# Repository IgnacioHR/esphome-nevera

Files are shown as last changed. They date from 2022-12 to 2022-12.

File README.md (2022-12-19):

# Nevera - Fridge Alarm

## Introduction

We experienced an issue with our fridge where the door was difficult to open immediately after it had been closed. This is due to the fact that the cold air inside the fridge reduces in volume, causing the rubber on the door frame to take longer to fill the void. If you try to open the door too early, it puts additional strain on the rubber. In order to address this issue, we have developed a device that serves several purposes.

## Demo

Check out this video: <https://youtu.be/vCrqtjIsVMY>. The first 30 seconds show the device operating normally, while the rest of the video demonstrates a bug that we have yet to fix.

## Project Goals

1. Sound a loud alarm if the fridge door is opened too early (the time can be adjusted)
1. Inform the user how long they should wait to open the door
1. Provide information to a home automation system (HA) about the status of three sensors:
   1. Main door sensor (open/closed)
   1. Wait time sensor (on/off)
   1. Alarm sensor (on/off)
1. In addition to the above sensors, We have also added a statistics sensor to the HA to track the following information over the past 24 hours
   1. The number of times the firdge door was opened/closed
   1. The amount of time the fridge door was left open

## Bill of Materials (BOM)

- ESP32 single chip
- MAX7219 8x8 LED matrix - used as the main display (communication via SPI protocol)
- Voltage regulator to 3.3v - (used to power the ESP32 with an external 5v power supply)
- Active buzzer (alarm - Google "MH-FMD")
- 8 channel bi-directional logic level converter (Google "HW-0108")
- Reed Switch Sensor Magnetic (and magnet)

## Images

Wiring phase:

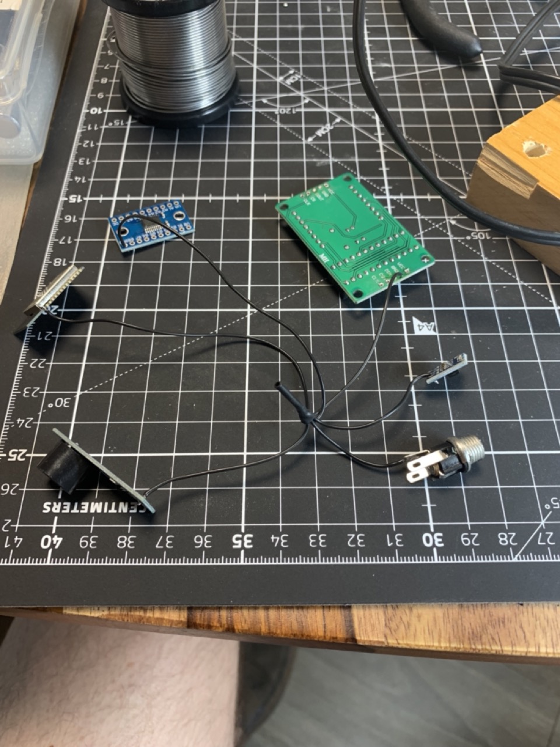
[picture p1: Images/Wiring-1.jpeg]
Wiring 1, GND

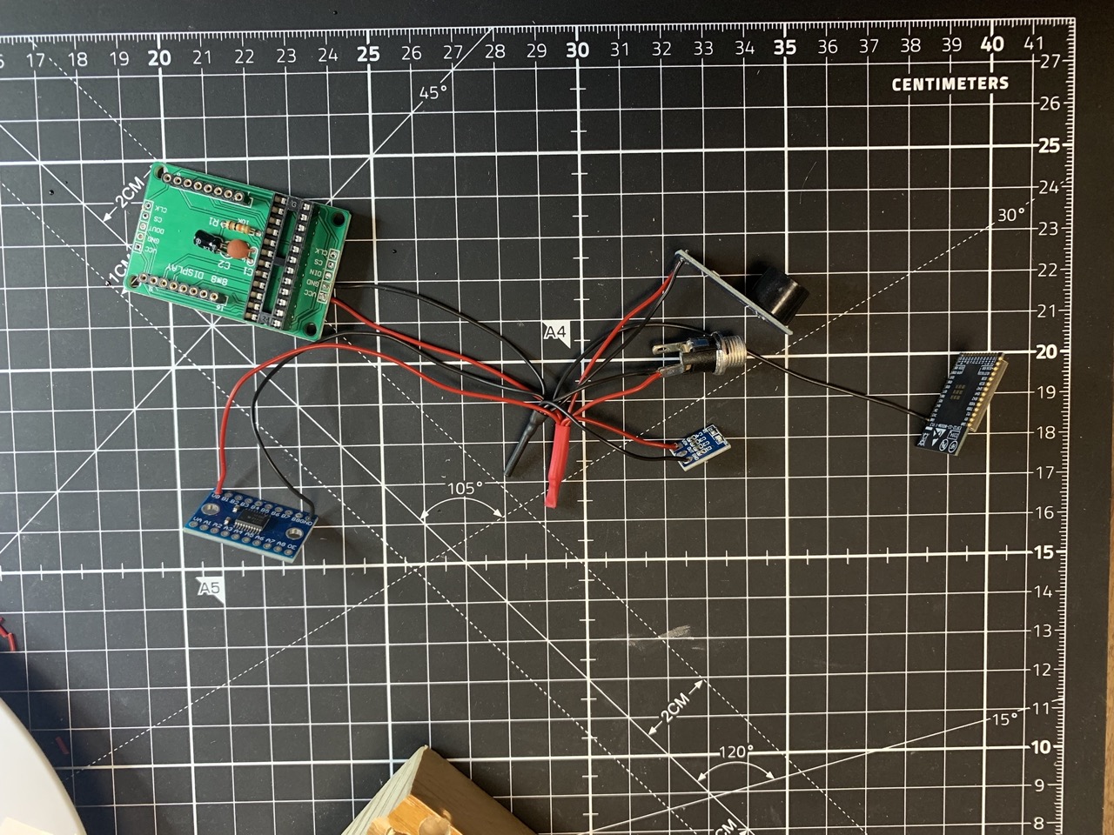
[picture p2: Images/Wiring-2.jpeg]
Wiring 2, +5v

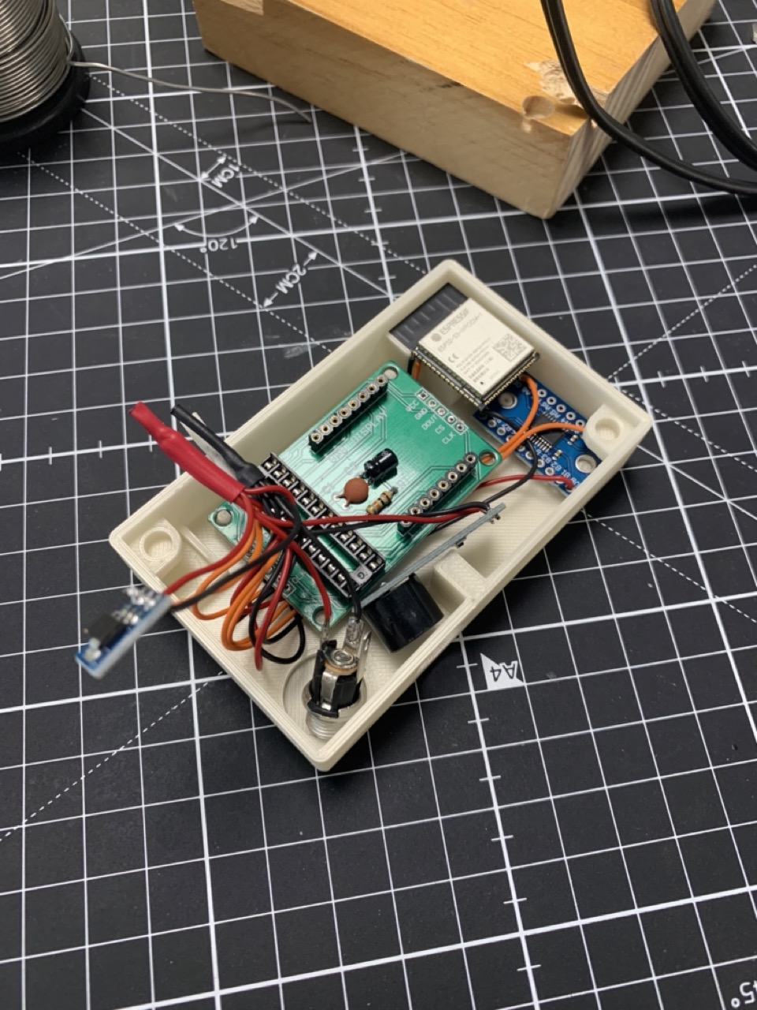
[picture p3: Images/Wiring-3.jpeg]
Wiring 3, +3.3v

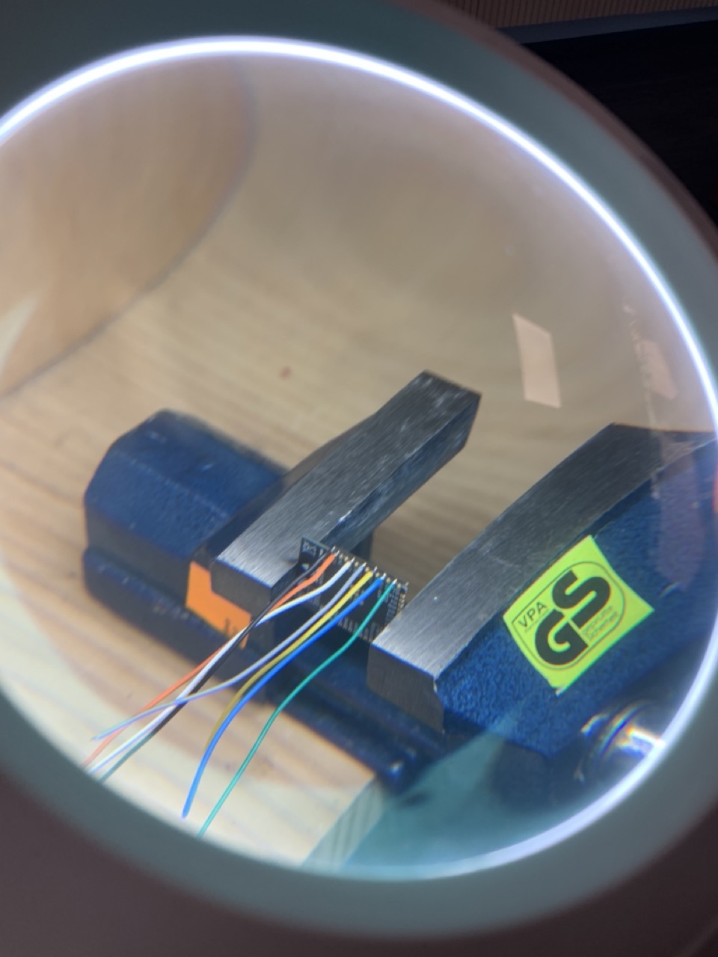
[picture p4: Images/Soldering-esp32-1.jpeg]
Soldering esp32, details

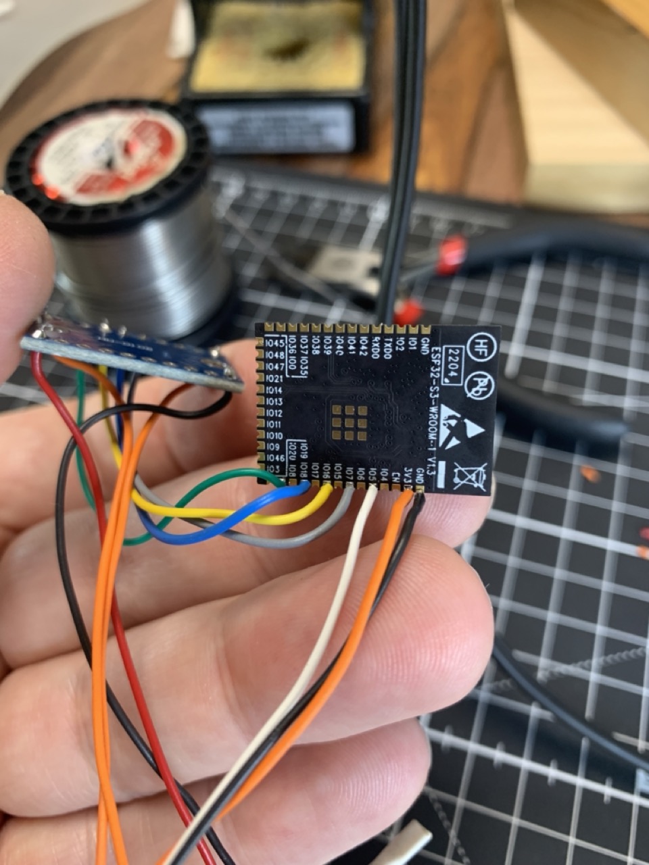
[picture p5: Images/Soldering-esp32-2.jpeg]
Soldering esp32, details

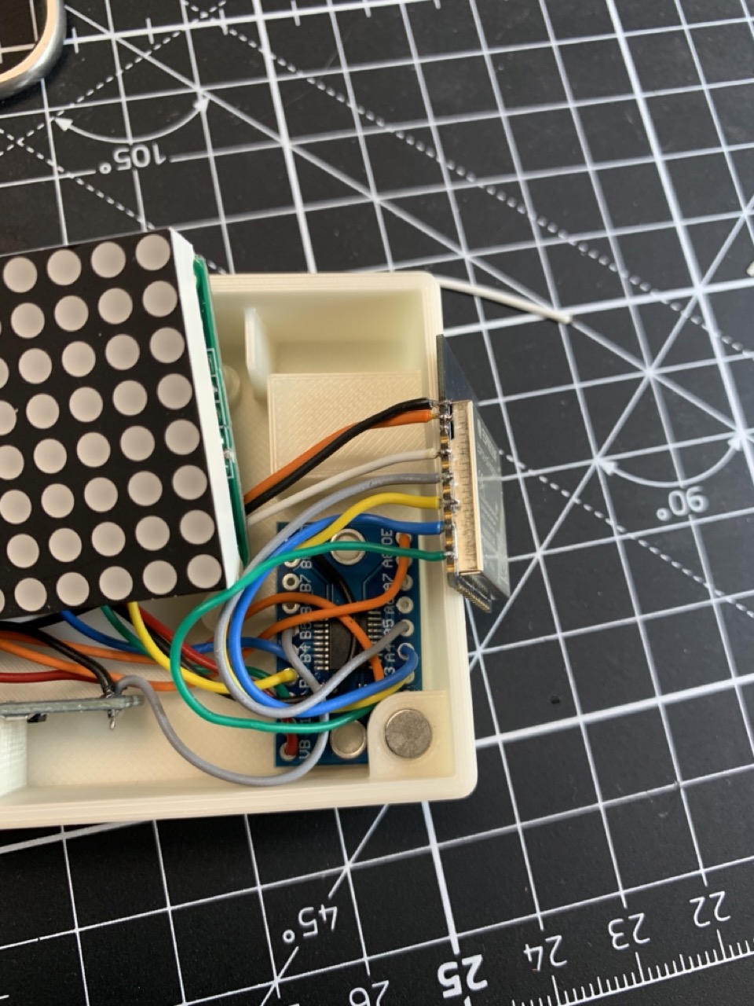
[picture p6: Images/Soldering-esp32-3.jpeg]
Soldering esp32, details

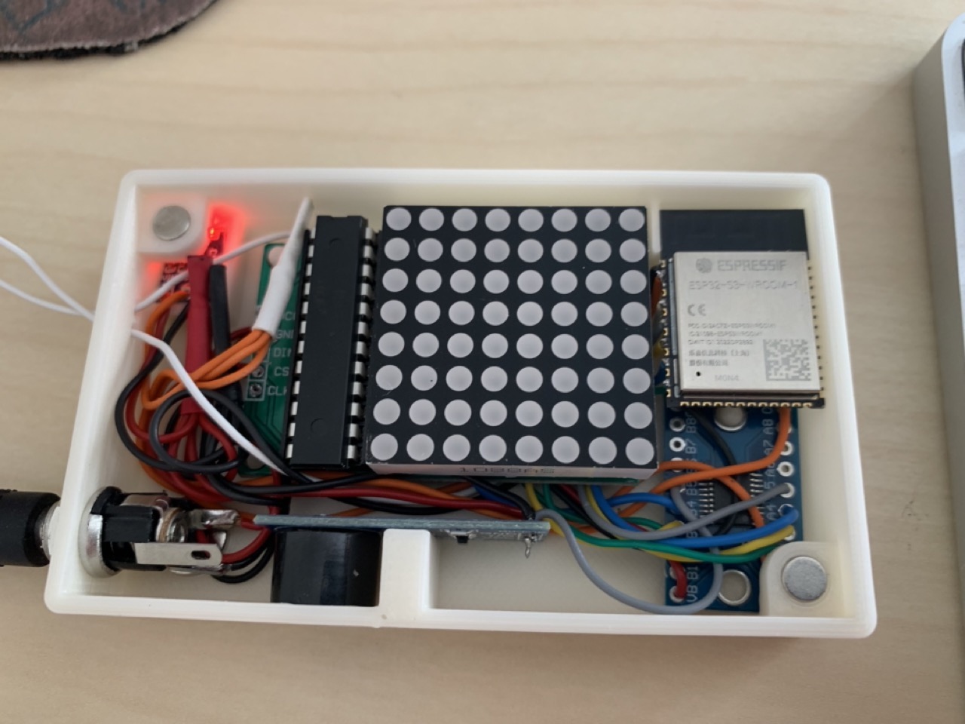
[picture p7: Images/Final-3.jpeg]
Final, open

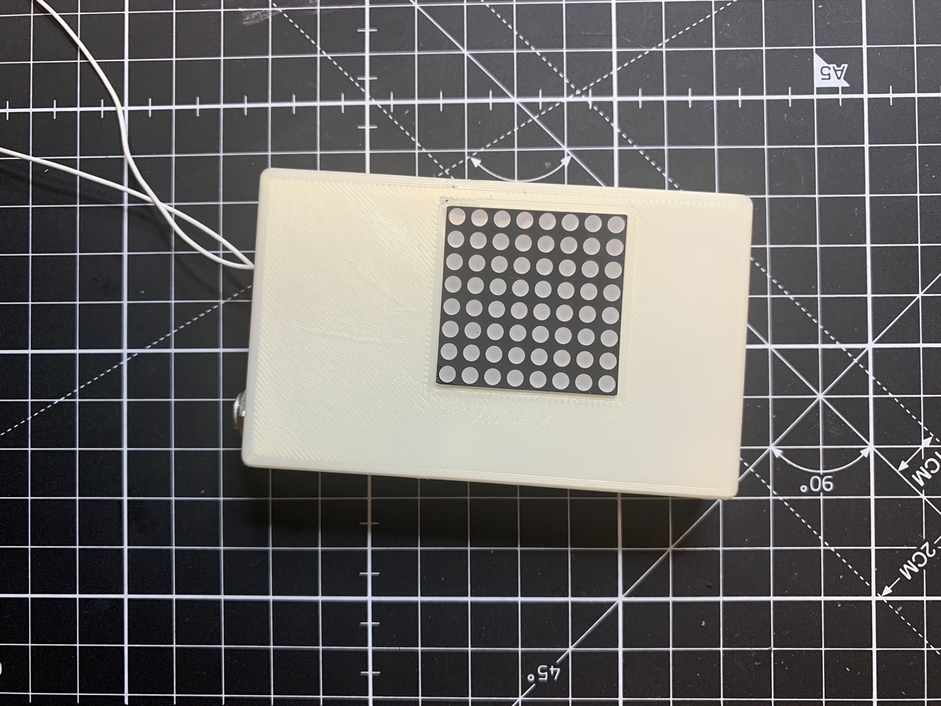
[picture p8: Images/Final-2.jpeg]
Final, closed


## Schematics

TODO

## Case stl for 3d printing

Files in the 3d-printing folder corresponds with the enclosing case. I'm using 4 cilynder 5x3 mm magnets to secure the case closed while allowing me to open it when needed.

Check out the following files:

- 3d-printing/Nevera-case-bottom.stl
- 3d-printing/Nevera-case-top.stl

## Prerequisites

- ESPHome development environment <https://esphome.io/index.html>

## Installation instructions

To install the device, simply copy the file 'nevera.yaml' to your ESPHome development environment and burn it onto a chip.

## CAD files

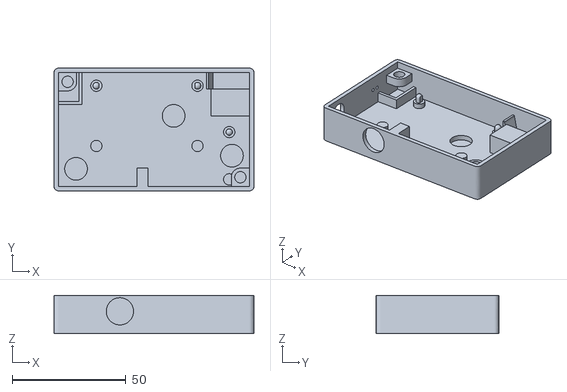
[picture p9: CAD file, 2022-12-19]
3d-printing/Nevera-case-bottom.stl
88.0 x 54.0 x 16.8

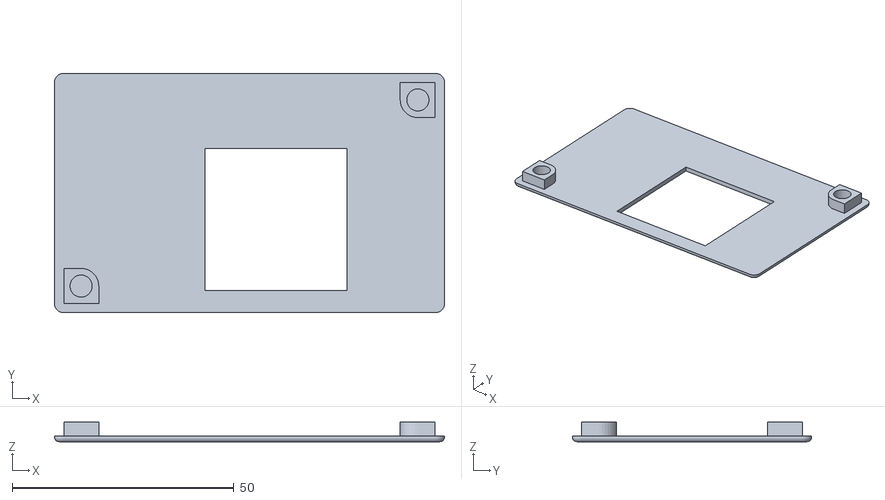
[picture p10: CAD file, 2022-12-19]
3d-printing/Nevera-case-top.stl
88.0 x 54.0 x 4.40

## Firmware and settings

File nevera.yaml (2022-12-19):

# This file is copyright Ignacio Hernández-Ros ignacio@hernandez-ros.com all rights are reserved
# You cannot earn money based on this work and cannot transfer it to anyone that might earn money
# based on this work.
# You can't sell this code. You can't produce the device described for commercial purposes
#
# esphome-nevera is a decive with a sensor that detects when the fridge door has been opened
# Once it is opened:
#   If the last time it was closed is less than 30 seconds, the alarm is turn ON
#   regardeless of the alarm status, the display shows an icon representing "door open"
# When the door is closed:
#   If the alarm was ON, turn it OFF
#   Start a counter down for 30 seconds to detect if it is opened too early
#   The display shows full white and every 30/64 milliseconds a led is turned down (randomly)
# When the count down ends, the fridge door can be safely opened again
#
# The implementation is based on the following devices:
#   SPI to communicate with the MAX7219
#   BinarySensor based on an incoming pin (the contact is magnetic)
#   Template Binary sensor to publish the state of the internal counter (like a tampering device)
#   Switch (internal) to turn the alarm on-off
#
#
#  IMPLEMENTATION NOTES:
#   - I've been extremely careful to avoid interferences between the display and the sensors.
#     Means there are no calls to update the display when the sensor changes. It is the
#     Lambda that render the display who takes care of the status.
#   - The code inside the lambda has been simplified a lot. On every "frame" the entire device
#     Matrix is transferred from the internal 8x8 bits representation to the data model of the
#     surrounding display.
#   - The display is turned "off" when the count down ends. And it is turned "on" when
#     the door has been opened.
#   - There must be a bug in the SPI, Display or binary sensor code that is weird. When the
#     door is closed, sometimes (not always) the display goes black. Internally the whole
#     count down process continues to run. If the door is opened, the alarm turns on, etc.
#     but there is no white representation and no leds are turned off (visually)
#   - Sometimes (randomly) when the fridge door is opened, the intensity is no longer level 15
#   - Sometimes (randomly) the lines are displaced one bit (right) or turned reverse color from a
#     specific led in the line.
#   - It looks like the BinarySensor based on GPIO might interrupt the Display routine (and the
#     SPI transfer) and this causes weird situations?
#
#
# Connections and pin assignments
#
# ESP32 GND    -> 1  -> MAX7219 GND
# ESP32 V3.3v  -> 2  -> MAX7219 VCC
# ESP32 V3.3v  -> 3  -> MAX7219 VCC En (chip enabled)
# ESP32 GPIO32 -> 8  -> Door open sensor IN White
# ESP32 GPIO33 -> 9  -> MAX7219 CS OUT Yellow
# ESP32 GPIO25 -> 10 -> MAX7219 CLK OUT Blue
# ESP32 GPIO27 -> 12 -> MAX7219 DIN OUT Green
# ESP32 GPIO14 -> 13 -> Sound Alarm OUT Grey

esphome:
  name: nevera
  on_boot:
    priority: 600
    then:
      - binary_sensor.template.publish:
          id: sensor_recien_cerrada
          state: OFF
      - binary_sensor.template.publish:
          id: sensor_alarma
          state: OFF

esp32:
  board: esp32dev
  framework:
    type: arduino

# Enable logging
logger:
  #level: VERBOSE
  level: INFO

# Enable Home Assistant API
api:
  encryption:
    key: "GenerateMe" # Visit https://esphome.io/components/api.html go down to "key" and copy the generated value

ota:
  password: !secret ota_password

wifi:
  ssid: !secret wifi_ssid
  password: !secret wifi_password
  domain: !secret wifi_domain # maybe you don't need this

  # Enable fallback hotspot in case wifi connection fails
  ap:
    ssid: "Nevera Fallback Hotspot"
    password: !secret captive_password

# captive_portal: # disable when using idf framework

#external_components: # enable if custom components are required
#  - source: components

switch:
  - platform: gpio
    internal: true
    pin:
      number: GPIO14
      mode:
        output: true
    id: out_alarma
    inverted: true
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

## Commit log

2022-12-19 add magnetic sensor to BOM
2022-12-19 Added images
    [Nevera - case bottom.stl, Nevera - case top.stl]
2022-12-19 Added stl files
    [Nevera-case-bottom.stl, Nevera-case-top.stl]
